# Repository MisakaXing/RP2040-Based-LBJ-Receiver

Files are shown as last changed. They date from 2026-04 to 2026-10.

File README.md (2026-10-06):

# RP2040-Based-LBJ-Receiver
# 致谢和免责

本项目参考了FLN1021/SX1276_Receive_LBJ  
本项目基于GNU-GPL开源，任何基于本项目的修改均需依相同协议开源  
本项目按“原样（AS IS）”提供，不提供任何明示或暗示的担保，包括但不限于特定用途适用性及非侵权性的担保。  
禁止用于非法用途，本项目仅作为学习POCSAG解码和SX1276无线模块的示例  
在法律允许的最大范围内，项目作者或贡献者不对因使用本项目或无法使用本项目而导致的任何直接、间接、附带、特殊、惩罚性或后果性损害承担责任，包括但不限于数据丢失、法律责任等。  

**使用本项目即表示您已理解并同意自行承担所有使用风险。**

# 1.1 硬件

您可以在/PCB文件夹中找到PCB Gerber，EDA工程文件，BOM表，原理图，在/Case文件夹找到外壳的3D模型，工程文件，请自行焊接组装

需要注意的是某些国产pico开发板的USB-C接口没有下拉电阻，这会导致无法使用PD充电器，请购买前向卖家确认好是否有下拉电阻，若不使用PD充电，可忽略本条

请提前在开发板上安装好MicroPython，版本需要大于等于1.28

推荐的电池容量是3.7v 1200-2000mah 预留的电池安装位置是35*53mm，可以修改R4/Rprog实现修改充电电流，默认充电电流是1A，Rprog和充电电流ICHG的换算关系是ICHG=1000/Rprog
PCB上电池接口为XH2.54，电池需要购买XH2.54**反向口**

PCB上不带锂电池保护电路，购买的锂电池必须**自带保护板**！

如果使用JLC打样，请确保层压结构为JLC04161H-7628，使用其他PCB制造商请使用对应的阻抗计算工具计算阻抗，阻抗线宽度为0.356mm，需求阻抗50ohm  

## 2.1软件实现原理
### 基本原理

如果您对原理不感兴趣，请直接跳转到3.1刷入程序

中国铁路列车会在821.2375Mhz上以3w功率发送POCSAG1200数据，数据类型均为numeric，列车会分两次连续发送两条数据，范例如下：  
123 23 123 #Basic msg  
列车号 速度 公里标 其中公里标格式最后一位是小数点，即12.3km  
204U2390093130U-(2 9U- (-(202011720927939053465000 #extend msg  
解码规则如下

| 字段值 | 含义 |
|---|---|
| 204U | 两位ASCII标准码表示列车等级，在这里4U=K，即K字头 |
|2390|机车类型标识号，可以从/main/rp2040-main-program/locos.json找到|
| 0093|机车号|
|30|端位，30表示无端，31为A端，32为B端|
|U-(2 9U- (-(2020|四位的GBK编码汉字，表示当前线路|
|117209279|经度|
|39053465|纬度|
|000|未知|

所有信息都只会出现在对应的位置，位号固定  

将两条信息组合即成列车完整信息  

需要注意的是并非所有线路均有扩展信息的发送，部分线路只有基础信息，甚至不少动车组列车连基础信息都不发  
### 本项目实现

通过操控SX1276的寄存器，调整其为FSK Direct模式，DIO1和DIO2分别输出1200hz时钟和采集到的bit，利用树莓派的PIO在时钟的上升沿采样DIO2的数字输出，寻找同步码并解码POCSAG，进行2bit BCH纠错后依上述解码方式解码，格式化成json返回给主函数，以上代码实现请见lbj_receiver.py

## 3.1 设备管理：LBJ Manager

原 PicoUpdater 和 LogViewer 已合并为 [LBJ Manager](lbj_manager/README.md)，源码统一在 `lbj_manager/`。固件更新、硬件检查单和历史查看共用一个窗口、一个设备选择器；接收器固件仍在 `rp2040-main-program/`。

连接接收器的数据 USB，点击「扫描设备」。只发现一台 Pico 时会自动选中，顶部显示绿色「已自动选中 Pico」；多台时请手动选择。选择普通版 `main` 或 W 版 `Wireless-Enabled`，再点击「检查并更新固件」，或用「从 ZIP 刷入」离线更新。刷入前检查硬件兼容性及固件包依赖，包含 DMA 与设备保护模块。**刷入会删除历史，先导出备份。** 更新、自检和历史读取不能同时占用串口。

固件 ZIP 可直接拖到刷入区域，先载入校验，再点击刷入并确认；拖入不会改写设备。历史页支持将 JSON / JSONL / TXT / LOG 文件拖到日志区域直接导入。

源码运行：

```sh
python3 -m pip install -r lbj_manager/requirements.txt
python3 lbj_manager/lbj_manager.py
```

预打包工具可在本项目 [Releases](https://github.com/MisakaXing/RP2040-Based-LBJ-Receiver/releases) 查找；旧 Release 中的两个独立工具不包含本次整合更新。Apple Silicon 的 `.app` 构建配置见 `lbj_manager/LBJ Manager.spec`。

*如果要使用自动更新功能，请确保不要更改Main.py的版本变量*
```python
Program_ver = 2.1
```
## 4.1 历史记录：LBJ Manager

在 LBJ Manager 的「历史记录」页读取或导出设备历史，也可导入 SD 卡中的 JSONL 文件，按车次、车型和时间筛选，查看坐标与原始报文。设备读取采用分段传输和 SHA-256 校验；读取时暂停接收，结束后重启恢复，少量未落盘记录可能丢失。

普通版机内历史最多保存2000条；实际剩余空间不足时会提前停止保存，并显示红色 MEM FULL，实时接收和显示不受存储满限制。固件预留16KB空间，并在每次写入前检查本次写入所需的整块空间。格式化机内历史后可恢复保存；历史不会自动覆盖。同时可外接SD卡扩展，SD卡必须格式化成FAT32格式才能被识别

SD卡热插拔功能因影响屏幕刷新已被取消，在开机状态下插入SD卡需要在设置中手动Mount-SD

W 版机内历史最多保存9999条，桌面查看器分批加载，避免一次性插入全部记录导致界面长时间无响应。

## Known Issues
当前代码理论上兼容RP2040（pico1）和RP2350（pico2）但是Pico2会出现各种不可预知的问题比如屏幕花屏，反色等，建议各位使用pico1  

## Update Log Jun2 2026
PCB上增加了一组肖特基二极管，现在休眠状态下按电源键也可以唤醒屏幕了  

重构了屏幕驱动，加快了屏幕刷新速度  

SN码来源更改为Pico的芯片唯一ID的Base36格式，故刷入器的SN码写入功能已被弃用，刷入器加入了硬件焊接检查功能

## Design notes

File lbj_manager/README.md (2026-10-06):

# LBJ Manager

PicoUpdater 与 LogViewer 的整合版，版本 `3.0.5-preview`。一个窗口、一个设备选择器，包含「设备管理」和「历史记录」两页。仓库内原来的两个工具目录已由本目录替代。

## 使用

安装 Python 3.11 或更高版本及依赖，运行唯一的主入口：

```sh
python3 -m pip install -r lbj_manager/requirements.txt
python3 lbj_manager/lbj_manager.py
```

Apple Silicon 版 `LBJ Manager.app` 内嵌 Python 和依赖，可直接双击。没有开发者证书签名或公证；其他 Mac 的安全设置可能要求手动允许打开。复制整个 `.app`，不要只复制里面的可执行文件，也不要破坏 Framework 的符号链接。

## 工作流程

- 接收器接入 USB 后点击「扫描设备」：唯一 Pico 自动选中，在顶部设备选择器旁显示绿色「✓ 已自动选中 Pico」和端口，底部也显示扫描结果。启动时自动选中同样有提示；后台扫描不抹掉确认，不切换设备。多台设备时手动选择。没有检测到 Pico 或扫描失败时不能刷入、读取或自检。
- 设备管理：选择普通版或 W 版，在线更新、强制刷入、离线 ZIP 刷入和硬件检查单。刷入前复核硬件兼容性。**刷入会清除设备历史，先到历史页导出备份。**
- 历史记录：读取设备、导出原始 JSONL、导入本地日志，按车次、车型、时间筛选，查看坐标、地图与原始报文。9999 条记录分批显示，未知速度保持 `---`。
- 更新、自检、读取和导出共用串口锁，不能同时操作同一台或另一台接收器。预检取消后尝试重启恢复接收；恢复失败、USB 拔出和部分写入会明确提示，不宣称设备已经恢复。
- 读取设备历史会暂时停止接收并在结束后恢复。硬件检查也会暂停接收。界面导航和设备扫描本身不会停止接收。
- 页面快捷键：Windows / Linux 使用 Ctrl+1、Ctrl+2，macOS 使用 ⌘+1、⌘+2。显式绑定 `KeyPress`，不匹配鼠标按键。
- 刷入后重启：发送指令后释放旧串口，不再等待重启指令的 EOF，避免 Windows 在 USB 断开时出现 `ClearCommError`。在线和 ZIP 刷入都检查同一接收器的 USB 断开、重连；未确认时显示「文件写入完成，重启待确认」，不会重复重启或误报固件运行正常。USB 重连不等于屏幕、射频已通过测试，仍需观察设备。

## 拖拽导入

- ZIP：将一个固件 ZIP 拖到设备管理页的「拖入固件 ZIP」区域，或「从 ZIP 刷入」按钮。软件只在电脑上校验包内版本、当前分支、运行文件与 DMA / 保护依赖；通过后显示文件名和版本。点击「刷入已载入 ZIP」才进入原有硬件预检与清空数据确认流程。**拖入本身不访问串口、不刷写、不清历史。**切换固件分支会清除已载入的 ZIP，刷入前会再次校验。
- 日志：将一个 `.json`、`.jsonl`、`.txt` 或 `.log` 历史记录文件拖到历史页的「拖入日志文件」区域，或「导入日志」按钮，直接开始后台解析。无效文件不覆盖当前已载入的记录。
- 支持中文、空格与花括号路径。多文件、文件夹、拖错区域和任务进行中的拖入会给出底部提示。
- 原有文件选择按钮保留。拖拽使用 [TkinterDnD2 的原生 TkDND 支持](https://github.com/Eliav2/tkinterdnd2)，Apple Silicon App 已内嵌 arm64 库；源码环境缺依赖时会明确提示并回退到按钮。

## DMA / 新增文件

两个分支的在线清单与离线 ZIP 都识别 `pio_dma_rx.py` 和 `device_protection.py`，依赖文件先写、`main.py` 最后写。W 版另含 `history_store.py`、`wireless_portal.py`。

`3.0.5-preview` 修复 W 版遗漏 `boot.py` 的问题：两版的在线更新与 ZIP 都保留此文件，在 `main.py` 前写入，恢复 `STARTING... / LOADING FIRMWARE` 开机画面。主程序使用 `_boot_display` 交接时，包内缺少 `boot.py` 会在刷入确认之前被拒绝；开机文件同样接受语法和 UTF-8 校验。没有早期开机画面交接的旧固件仍可不带 `boot.py`。**旧 App / exe 不会自动获得这项工具修复，必须使用重新打包的工具。** 已丢失开机文件的设备不会因电脑源码修改自动恢复，需要补写匹配该硬件的 `boot.py`；无需为此清空历史或整机刷入。

整合版额外解析包内 Python 文件的本地模块依赖：新固件如果导入 DMA / 保护模块，ZIP 或在线下载必须包含对应文件；语法错误、缺文件、无效 UTF-8 均在刷入前阻止。没有新增依赖的旧固件仍可使用。**这不是设备端逐字节刷写校验**：复制仍依赖 mpremote 的写入结果；历史导出则使用长度与 SHA-256 校验。

W 版核心自检已按当前硬件读取 GP46 的 VSYS/3，不再沿用旧的 GP41 电池测量；普通版保留 GP27 外部电池检测。

## 开发与测试

`lbj_manager.py` 是直接维护的唯一主入口，已内联两套主程序和历史传输引擎，不依赖旧工具目录或生成脚本。硬件自检使用同目录的 `solder_check.py` 与 `diagnostic_drivers/`。原有更新、检查单和历史传输的回归测试已迁入本目录，直接测试整合版，不需要恢复旧源码。

```sh
python3 -m unittest discover -s lbj_manager/tests -v
python3 lbj_manager/tests/gui_smoke.py /private/tmp/lbj-manager-gui
python3 lbj_manager/tests/drag_drop_smoke.py /private/tmp/lbj-manager-drop
```

GUI 测试创建真实 Tk 窗口，但 USB、下载与自检传输使用模拟对象，不会操作真实接收器。测试详情与边界见 `TEST_REPORT.md`。

原随附的 RTC 校时脚本保留在 `rtc_sync_gui.py`，可单独运行 `python3 lbj_manager/rtc_sync_gui.py`。它不在主 App 的导航里；使用时不要同时在 Manager 中对同一设备执行串口任务。

打包：在 arm64 Python 环境运行 `python3 -m PyInstaller "lbj_manager/LBJ Manager.spec"`。

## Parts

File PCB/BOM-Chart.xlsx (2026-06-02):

位号 | 值 | 封装 | 备注
U0 | N/A | SX1276模块 | 要868mhz (https://item.taobao.com/item.htm?id=560578002124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)
R1 | 0.4R | R0603
R2,R3 | 1K | R0603
R4 | 1K | R0603 | Rprog,需要修改充电电流的话更改此电阻
R5,R6 | 10K | R0603
R9,R10 | 4.7K | R0603
R7,R8 | 100K | R0603
C1,C2 | 10uf | C0603
C3,C4 | 0.1uf | C0603
U7 | DS3231S# | SOIC-16
U2 | TP4056 | ESOP8
D1 | N/A | LED0402 | 红色
D2 | N/A | LED0402 | 绿色
U1 | N/A | TFT2.8 | ILI9341驱动，2.8寸，不需要触摸
U8 | AO3401 | SOT23 | PMOS
U3 | SI2302 | SOT23 | NMOS
P1 | N/A | XH2-2.5490° | 90度卧式xh2.54接口
SW1,2,3,4,5 | N/A | 6X6X8 | 卧式直插按键开关
U4 | EC190708 | EC190708
J1 | BUZZER | 0905 | 3v驱动 有源
U6,U10,U11 | 1N5819 | SOD323 | 肖特基二极管
U5 | N/A | N/A | 树莓派pico开发板
U9 | N/A | SMA-KE | 卧式沉板SMA母头座子，直头偏脚，内孔
N/A | 2000mah | N/A | 电池最大大小为34x53x8mm 3.7V
N/A | M3*7+4螺柱 | N/A | 4个，用来架高屏幕
N/A | M3螺母 | N/A | 4个，在PCB背面固定螺柱
N/A | M3*8螺丝 | N/A | 8个，固定开发板和固定屏幕
N/A | 2.54排针4p | N/A | 1个，屏幕的SD卡引脚通常不焊排针，需要自己焊上

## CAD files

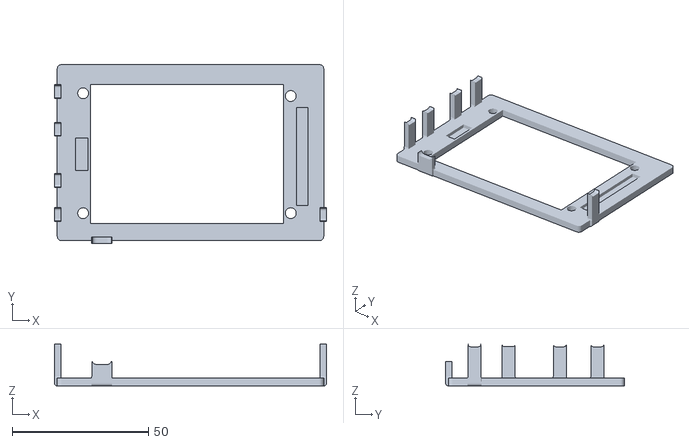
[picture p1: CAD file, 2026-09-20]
Case/CASE_V13_TOP_SCREEN_EDGE_IN0p7_TOTAL.stl
99.8 x 65.6 x 15.4

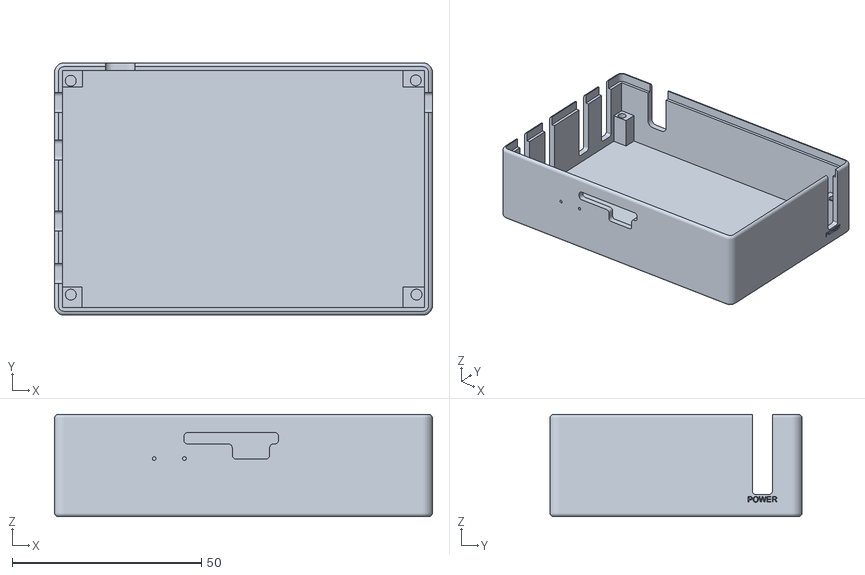
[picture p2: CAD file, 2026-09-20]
Case/CASE_V13_BODY_PCB_CLEARANCE_0p25.stl
99.8 x 66.6 x 27.0

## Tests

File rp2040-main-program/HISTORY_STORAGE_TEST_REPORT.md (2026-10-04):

# 普通版 5.12：历史容量与剩余空间保护

日期：2026-10-05（北京时间）。本次只更新普通版，未改 W 版或射频/DMA 配置。

## 行为

- 历史上限及 ABOUT 页同步为 2000 条；不会自动覆盖或截掉旧记录。
- 预留 16 KiB（不是 5 KiB）。写入前按 `statvfs` 的可用块数检查空间，额外计算本条 UTF-8 JSON 需要的整块空间及两个写入周转块。
- 达到条数上限或空间不足，持续显示红色 `MEM FULL`，停止历史队列和 Flash 追加；实时解码、显示和独立 SD 日志不受此限制。
- 文件系统读取、空间检查或写入异常显示 `SAVE ERR`，停止反复重试。只有写入与关闭/flush 均成功才发布索引、增加条数。
- 格式化历史后重新建立索引并检查空间，允许恢复保存。重启也重新检查；未完成的尾行会阻止继续追加，不会悄悄删除。
- 2000 是最大条数，不承诺任意长度的完整报文都能存满：若实际空间先不足，则提前保护。

## 自动测试

| 测试套件 | 结果 |
| --- | --- |
| 普通版固件 | 104 项通过（含 28 项新增存储测试） |
| Log Viewer | 27 项通过 |
| PicoUpdater | 75 项通过 |
| 合计 | 206 项通过 |

覆盖条数边界、预留空间与整块边界、大记录、Unicode 字节偏移、可用块/块大小、空间检查失败、ENOSPC、短写、关闭失败、队列清理、旧记录超过新上限、不完整尾行、格式化重启用、存储让步于射频积压和写入间隔、SD 独立保存、警告优先级、仅状态变化时刷新、停写后 BASIC/EXT/FULL 画面继续更新。

## 普通 Pico 实机

1. **Unicode 保存/索引：通过。** 两条含中文车型的 JSON 实际写入临时文件；第二条字节偏移与第一条实际长度一致，读取内容相同。
2. **真实 2000 条边界：通过。** 临时文件中先写入并扫描 1999 条短样本，随后使用生产保存函数写入第 2000 条；索引和条数均为 2000。再尝试 10 次保存/入队均被拒绝，文件大小保持 278,000 字节，末条可正确读取。此测试不意味着 2000 条长 FULL DATA 报文必然放得下。
3. **真实低空间：通过。** 使用临时填充文件将实际 Flash 空闲压至 24,576 字节。生产策略在追加前触发保护，历史文件仍为空、索引和计数均为零；后续入队被拒绝。此次拒绝约 9.8 ms。
4. **空间恢复：通过。** 清除临时填充文件后保护仍锁存；按格式化同样的初始化路径重新检查，保存恢复正常。
5. **PIO/DMA—解码—LCD—Flash：通过。** 32 个不同车次的已知完整 POCSAG 样本通过实际 PIO 状态机、DMA 和生产解码器，不是直接注入 UI 回调。正常保存阶段 16 条全部更新屏幕并落盘；RAM 中模拟空间保护阶段另外 16 条仍更新屏幕、但新增历史为零。同步增加 32，不可纠正码字增加 0，DMA 溢出/丢弃、回调错误及 UI 丢弃均为 0。存储服务最大用时约 138 ms。
6. **清理、重启、读回：通过。** 全部临时填充/样本文件已删除，真实历史未被测试样本污染。机内 5.12 `main.py` 与提交源码逐字相同，射频/DMA/保护依赖与本地相同，配置与升级前备份逐字相同；最后硬件重启恢复正常程序。

第 5 项为数字接收链路测试，不是空口发射、天线或现场接收率测试。测试脚本仅在 RAM 中使用无 GPIO 输出的 PIO 数据源，结束后硬件重启撤销全部测试状态；未改写射频库、DMA 库或配置文件。

## 真实接收观察边界

收尾被动日志 75 秒中，主循环及射频线程运行，DMA 启用，线程/SPI/回调错误和丢弃均为零；截至最终状态快照，新启动实例 `words=0`、`syncs=0`。没有收到新的自然空口报文，因此不能将此版本宣称为已解决此前所有“不接收”现象，或把缺少自然报文视为接收率验证通过。

## 用户数据处理

经用户明确授权，原有 2006 条历史已在备份验证后清空；保留机器配置及其他文件。原历史 976,885 字节完整 JSON 校验通过，备份位于 Mac：

`/Users/xinghening/Documents/Codex/LBJ_STANDARD_STORAGE_GUARD_2026-10-05/history-before-clear.jsonl`

最终文件系统空闲 983,040 字节；实机测试临时文件已删除，无新增测试车次留在真实历史。

原始测试日志、固件读回哈希及部署前配置备份保存在同一 Mac 目录，不包含在 Git 提交中。

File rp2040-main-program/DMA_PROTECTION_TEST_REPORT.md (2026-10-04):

# DMA、温度与低电量保护验证

> 本文保留保护功能阶段的原始测试记录。后续 DMA/AFC 修复与 5.11 / 5.13-W 提交前验证见 `DMA_RECOVERY_TEST_REPORT.md`；下文版本和“未推送”状态对应当时测试阶段。

日期：2026-10-04。普通版 5.10；W 版 5.12-W。两台设备已刷写，未提交或推送 GitHub。

## 行为

| 条件 | 两版行为 | W 版附加行为 |
| --- | --- | --- |
| 核心温度 >45°C | 温度读数标红 | 相同 |
| 核心温度 >60°C | 顶栏红色 HIGH TEMP | 关闭 AP；无线设置显示高温禁用原因 |
| 温度降至 ≤55°C | 解除无线高温锁定 | 依照原先保存的无线开关恢复；不会擅自开启原本关闭的无线 |
| 电池 <10%，无 USB 供电 | 顶栏红色 LOW BAT | 相同 |
| >60°C 且 <10%，无 USB 供电 | 两项警告每 2 秒交替 | 相同 |
| 电量 0%（补偿后的电压 ≤3.45 V），无 USB 供电 | 提示停收约 1 秒，关闭射频采集与屏幕，确认停收后降至 18 MHz | 同时关闭 AP |
| 保护后检测到 USB 供电 | 连续两次确认后硬件重启，重新完成 POST | 相同；保留原设置 |

普通版保留原 +0.174 V 电池补偿；W 版保留 1.07 倍补偿。普通版正常运行 200 MHz，W 版 150 MHz，不改变正常接收频率或射频参数。USB 状态每秒采样；温度与电池每 5 秒采样。警告交替与局部重绘无阻塞等待；仅低电量终止接收流程包含提示和保护等待。

## DMA

普通版已移植 W 版的 PIO→DMA 采集路径：512 个 32 位字的环形缓冲，两个 DMA 通道。运行时检查 DMA 支持，初始化失败回退原 FIFO。保留溢出与丢字计数，不把“队列没有丢弃”等同于射频完全没有丢码。

停收时关闭 PIO、数据与重载 DMA，并使 SX1276 进入 FSK Sleep。射频参数仍为 821242368 Hz、PPM 6、12.5 kHz 带宽、硬件 AFC、AGC 关闭、LNA 0x23。PicoUpdater 已同步模块清单及刷写顺序；仍兼容旧版固件包。

## 自动测试

- 普通版固件：58 项通过；W 版固件：220 项通过。
- PicoUpdater：普通分支 75 项、W 分支 76 项通过。
- 合计 429 次测试执行；两个分支有重复用例，不代表 429 个独立测试场景。
- W 网页真实 TCP/EventSource 与 Chrome 三客户端测试通过，覆盖历史权限、实时回退、20 秒超时、时间和导航。
- 手机、平板、电脑布局测试通过，无横向溢出；360×640 小屏仍需要纵向滚动，不承诺所有屏幕一屏放下。

## 实机专项

普通板 S/N：e66368254f677426。W 板 S/N：018540bc4336e6b4。

两板实测 DMA 连续有序字、环形回绕、重载计数、故意溢出计数及停止/重置。以独立 PIO 状态机生成输入，暂停消费 1.5 秒仍保存 56 个字，PIO FIFO 未满。

两板实际执行 LCD 警告绘制、射频与 DMA 停止、射频 Sleep、关闭背光、18 MHz 降频及重启恢复。温度、电量和保护中的 USB 插入返回值采用 RAM 注入，不加热设备、不耗尽电池，不制造历史车次。W 板实际关闭/恢复 AP，并验证无线高温提示及 55°C 回差。

最初 W 板在停收退出 core 1 后的保护流程出现 USB 无响应。改为停收后让 core 1 保持空闲驻留，避免退出线程；修改后完整通过 18 MHz 保护与 USB 重启路径。结果不支持“18 MHz 必然过低”，但底层线程退出/Flash 锁定关联仍是推测，未证明具体固件根因。生产代码没有加入测试用看门狗。

停收异常分支已加回归测试：只有 receiver.stop 成功才确认已停收；若失败，保护不执行降频。

## 普通版六分钟联合测试

按正常接收→历史翻页→正常接收→模拟高温低电量并翻页运行。实际绘制 273 次历史翻页，历史条数 1204→1222，持续接收真实射频车次。两项顶栏警告均出现。

DMA 溢出、DMA 丢字、FIFO 满、接收线程异常及 UI 队列丢弃均为 0；DMA 峰值 14/512 字。仍存在无线信道 BCH 不可纠正码字及重同步，不能据此断言所有空中报文均成功接收。

首次逐行核验 1229 条落盘 JSON 均有效；追加接收后的最终核验为 1274 条，仍无无效行，首/中/末记录读取正确，待写队列清零。设备主程序和新模块与本地逐字节一致，移除临时测试入口后硬件重启恢复正常 DMA 接收。检查脚本曾误将 REPL 的不可变总数快照当作实时计数；已改为与实际可变索引长度对照，确认不是历史文件损坏。

## W 版六分钟联合测试

同样执行四阶段对照，机内历史共绘制 316 次（正常 157、高温低电量 159）；SSE 所有者发起 119 次历史请求，其中 118 次完成，阶段切换时最后一项主动取消，无错误响应。温度注入 61.2°C 时实际 AP 关闭，HIGH TEMP/LOW BAT 均出现；恢复真实温度 43.4°C 后，按原保存的开启状态恢复 AP。

初始无同步，出现此前已存在的 profile_op_mode 恢复；约第 5 分钟才开始捕获射频。历史 1639→1640，采集超过 2600 个字；DMA 溢出、丢字、FIFO 满、UI/历史队列丢弃、线程异常、网页及存储错误为 0。仍存在 BCH 错码和重同步，不能承诺全报文接收。此轮没有在“网页历史负载开启”阶段获得实际射频车次，因此不单凭本轮证明该组合下接收性能完全不受影响。

最终逐行核验 1640 条历史全部有效，首/中/末记录可读取，待写队列为 0；七个部署文件逐字节核验，正常主程序已恢复，无临时测试入口。硬件重启后 AP 与 512 字 DMA 接收正常初始化。

## 测试范围

最后对正常主程序并行采集 65 秒日志：两台均继续采集射频字流，DMA/FIFO 溢出与丢字、线程错误、UI 丢弃仍为 0。W 版 AP 开启时出现实际地址与解码活动，网页和存储错误为 0；仍有信道错码，未将其掩盖为“全报文通过”。

未切换 Mac 网络，未执行真实手机经热点的端到端测试；板上网页压力测试使用 RAM socket 替身调用生产处理逻辑。未重新插入 SD 卡、人工逐个按键、物理拔插 USB 或实测耗尽电池。此前现存历史未格式化或删除；最早诊断快照前暂停可能损失当时尚未落盘的队列记录。短时压力测试不替代数日老化或有已知发送总数的射频丢包率测量。

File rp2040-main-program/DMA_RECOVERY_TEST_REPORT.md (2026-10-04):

# DMA/AFC 修复及提交前验证

日期：2026-10-04（北京时间）。普通版发布版本 5.11；W 版 5.13-W。

实机专项在递增版本号之前完成，设备测试时版本为 5.10 / 5.12-W。
本次发布仅在已验证执行代码上递增版本号，并更新测试和文档；没有再次刷写设备。

提交前自动回归：普通版固件 76 项、W 版固件 238 项通过；对应 PicoUpdater 测试 75 / 76 项通过。合计 465 次测试执行，两分支包含重复场景。测试需从固件目录运行，或设置 PYTHONPATH=rp2040-main-program。

## 修复范围

- 保留 512 个 32 位字的 DMA 环形缓冲、射频频率、PPM、带宽、增益及正常 CPU 频率。
- 连续直接模式的 AFC 不会自动为每个新突发重新计算。未同步时仅在无积压的新前导码上安全重捕获；连续采样但 15 秒没有同步时有界恢复。已同步负载不重启，寄存器查询最多每秒四次。
- 重新捕获按序停止 PIO/DMA、清 FIFO/移位状态、恢复 PIO 指令入口、重置 DMA，再请求带 PLL 重锁的接收重启。
- 只放行 PLL 已锁定但 ModeReady/RxReady 尚未就绪的特定 FSRx 状态，避免原工作模式检查反复重新配置；其他配置错误仍检查。
- BCH 纠错表改为 1024 个 uint32 的定长数组。实机重建旧字典约占 14048 字节，新数组数据区 4096 字节，另有少量对象开销；接收线程启动前 GC。
- 诊断附加 RAM 占用曾使普通版线程栈及历史索引分配失败；这不证明所有正常程序不同步都由内存问题引起。
- 同步已完成的 DMA、温度和低电量保护改动；W 版同时包含网页历史功能。
- PicoUpdater 在两种硬件配置中上传 DMA / 保护模块，并在 main.py 之前写入，保留对旧固件包的兼容。

## 实机结果

设备：普通版 e66368254f677426；W 版 018540bc4336e6b4。

| 测试 | 普通版 | W 版 |
|---|---:|---:|
| 同一 DCLK/Data 同时送 DMA 与直接 FIFO | 2201 字、0 差异 | 2226 字、0 差异 |
| 完整 BASIC+EXT 输入：FIFO / DMA / 短计数重载 | 各 32/32 正确 | 各 32/32 正确 |
| 强制 +18.31 kHz AFC 错误后的实际恢复 | 约 15 秒 | 约 15 秒 |
| 最终正常程序硬件复位启动 | 5/5 | 5/5 |
| 15 分钟现场同步次数 | 28 | 10 |
| 15 分钟新增落盘历史 | 15 | 6 |
| 15 分钟 DMA 最高占用 | 35/512 | 4/512 |
| 15 分钟 DMA 溢出 / 丢字 / 线程错误 | 0 / 0 / 0 | 0 / 0 / 0 |
| 60 秒双核已知完整帧与屏幕并发 | 37 帧正确、127 次翻页 | 37 帧正确、121 次翻页 |
| W 同时处理授权网页历史请求 | 不适用 | 121 次、正确序号 |
| 全量历史解析与索引复核 | 1819 条、0 无效 | 2256 条、0 无效 |

完整回放共 192 帧、6720 输入字，双核并发另有 74 帧；模拟报文不写入历史。
并发后普通版实存 1821 条（开始前又新增两条真实历史），W 实存 2256 条；逐条核对索引与文件序号匹配。
两板均移除临时测试程序并硬件复位，恢复正常主程序。部署时 main.py、lbj_receiver.py 与当时本地修复逐字节一致，其他核对文件与测试前备份一致。

## 验证边界

- 五轮启动是硬件复位，不是同时断开 USB 和电池的真正断电冷启动。
- 受控回放经过实际 PIO/DMA 和生产解码链路，但绕过空中射频；物理 AFC 恢复另有实际寄存器故障注入验证。
- W 网页并发实机检查使用 RAM HTTP socket 模型运行生产服务代码，不是手机经过热点的端到端测试；未切换 Mac 网络，设备 TCP 自连接超时不计入通过项。
- 现场仍有 BCH 不可纠正码字，15 分钟普通版 164、W 版 43；不能等同于精确丢包数，也不能宣称所有空中报文都收到。
- W 在部分短窗口无输入字，随后未重启或写射频寄存器就自然恢复至 572 字、1 次同步。只读检查发现 FSRx 等待前导码，DMA/PIO 正常、无积压；不据此证明两台板卡灵敏度相同或没有弱信号漏收。
- 没有已知总发送数的受控 RF 源，不给出绝对接收率。短测不替代数日老化。

依据：[Semtech SX1276/77/78/79 数据手册，第 52、60、96–98 页](https://cdn-shop.adafruit.com/product-files/3179/sx1276_77_78_79.pdf)、[MicroPython DMA 文档](https://docs.micropython.org/en/latest/library/rp2.DMA.html)。

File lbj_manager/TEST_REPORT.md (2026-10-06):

# LBJ Manager 测试记录

日期：2026-10-06。版本：`3.0.5-preview`。环境：Apple Silicon Mac，Python 3.11.5，真实 Tk 窗口，PyInstaller 6.19.0。

## 结果

| 范围 | 结果 |
| --- | --- |
| 合并版自动回归 | 开机文件交付修复后 271 项全部通过，无跳过；新增 7 项交付专项，保留前轮 27 项重启测试 |
| 真实窗口集成与压力测试 | 开机文件交付修复后重跑 65 项通过；两套数字快捷键与鼠标导航事件均通过，无 Tk 回调异常 |
| macOS 原生拖放事件链 | 24 项检查通过，TkDND 2.10.2，无串口访问 |
| 独立目录运行 | 前轮将新目录复制到仓库外，232 项回归全部通过 |
| 已连接 Pico 的扫描按钮检查 | 前轮 12 项通过；本次重跑未检测到 Pico，未执行串口操作 |
| arm64 `.app` 与复制版本 | 本轮 3.0.5 新包与复制版本 21 项通过，启动/强制结束日志无异常；内嵌程序全部字节码及常量与测试源码匹配。未构建 Windows exe |
| 原更新 / 自检 / 历史回归迁移 | 102 项保留在新目录，已计入上述 232 项 |

旧硬件检查测试中强制要求 W 核心自检读取 GP41 的断言，已随测试迁移改为 GP46 VSYS/3，并明确断言不使用 GP41；不再跳过。另有测试验证引脚、取样中位数与换算。

2026-10-06 目录迁移：移除仓库根目录的 `pico_updater/` 与 `log-viewer/`，统一为 `lbj_manager/`。旧回归直接导入整合主入口，不再读取旧目录。移除依赖旧源码的生成器与测试回放加载器，直接维护 `lbj_manager.py`；保留原随附 RTC 校时脚本。旧目录的完整备份在仓库外，接收器固件没有改动。

## 已覆盖

- 全局串口任务锁：40 个线程同时抢占只能有一个持有者；旧任务、伪造同值令牌不能解除新任务锁。
- 设备选择：单 Pico 首次选择、启动后插入并点击扫描、多 Pico 手动选择、非 Pico 串口、Debug Probe、拔出和更换设备；后台扫描不自动替换操作目标。点击扫描会给出完成 / 未发现 / 多台 / 失败提示；扫描失败禁用操作，重试成功恢复。
- 自动选中提示：启动时与点击扫描时，顶部选择器旁持续显示绿色「✓ 已自动选中 Pico」与端口；底部同时给出文字确认。后台扫描不抹掉提示；手动选择显示「已选中 Pico」，断开或扫描失败不保留绿色确认。
- 导航快捷键修复：用户在 Windows 实机复现并确认旧 `<Command-1>` 被解析为鼠标按钮，导致点击历史后又切回设备页。本地改为按平台选择 Command / Control，显式 `KeyPress-1/2`。测试检查两平台绑定字符串、页面目标及无含糊数字绑定；真实 Tk 测试向导航按钮 Label 注入鼠标按下 / 松开事件，验证来回切页，并在 Mac Tcl 引擎中验证 Ctrl 数字键事件。这不等同于本机完成 Windows 操作系统实测。
- 文件拖放：通过真实 TkDND 的 macOS enter / position / drop 事件链验证区域、按钮及其 Canvas / Label 子控件。中文、空格、花括号与大写后缀；单文件、类型 / 区域错误、损坏 ZIP、分支不符、设备忙碌；ZIP 仅载入、再次点击才进入既有预检确认，分支切换清除已载入包；日志直接导入、无效记录保持原数据，线程失败释放加载状态。明确禁止串口、刷写与设备历史命令。
- 主线程调度：1000 个后台回调有序执行，不从后台调用 Tk；任务失效、窗口关闭和回调超量不会误执行更新。
- 更新与恢复：取消、兼容性拒绝、线程启动失败、命令无输出或没有换行时的超时、USB 恢复失败、部分刷写、刷写中关闭窗口。
- 重启专项：重启不跟随 EOF、不退出旧 raw REPL，关闭旧串口后仅枚举 USB。Windows `ClearCommError`、发送失败、关闭失败、枚举失败、断开后未返回、未观察到断开均不能误报确认；同一 USB 序列号变更 COM 端口可识别，其他接收器不能冒充。在线与 ZIP 刷入共用完成提示；复制失败不发送重启，重启待确认不重复发送，警告只弹一次，普通写入错误仍失败。
- 固件包：普通 / W 两分支的在线清单、平铺 / GitHub 目录 / Windows 分隔符 ZIP；DMA 与保护模块先于 `main.py` 写入；直接读取两工作树的当前固件生成 ZIP，逐文件对照提取内容。
- 开机文件交付修复：移除旧测试中错误的“W 清单不包含 boot.py”断言。两版实际固件 ZIP 必须保留含 `LOADING FIRMWARE` 的 boot.py；新增测试覆盖 W 在线下载完整字节、两版三种 ZIP 路径、在线与 ZIP 两种清空/复制工作流（共 12 组子场景），验证 boot.py 写在 main.py 前，模拟设备启动交接保留画面。新版缺 boot.py 在确认之前拒绝；boot.py 写入失败保持部分刷入警告、不写 main.py、不重启。无交接的旧固件仍可刷入，注释/普通字符串不误判，语法损坏或非 UTF-8 的 boot.py 拒绝。
- 新增文件负向测试：新固件缺 `pio_dma_rx.py` 或 `device_protection.py` 时在确认刷入之前拒绝；旧固件未导入这些模块时仍接受。语法损坏、无效 UTF-8、不可读源码拒绝；注释中的 import 不误判。
- 历史传输：4096 字节分段、完整长度与 SHA-256、中文跨块、数据损坏、截断、空文件、恢复失败、原子导出不覆盖旧文件、读取与更新不能同时启动。
- 历史展示：9999 条全部保留，`0D139`、中文车型、五位车号和 A/B、年/月/日时/分、未知速度 `---`、零值与非法坐标、跨午夜时间筛选。
- 真实 UI：9999 条分批渲染、筛选再恢复、150 次改变记录选择、80 次页面切换、最小窗口 1120×800、单地图标记、坐标与日期不裁切。
- 检查单：嵌入设备页、运行时不离开检查单、核心通过后等待确认、W 显示 VSYS、报告结束释放锁并返回运行日志。原有按键、屏幕、蜂鸣器、SD 工作流回归测试保留。
- 打包：arm64 可执行文件、权限、Framework 符号链接、bundle 本地完整性、内嵌 mpremote、任意工作目录启动、复制整个 `.app` 后再次启动。检查可执行文件的归档，确认包含新合并 UI 与固件依赖验证函数。

快捷键修复首轮真实 GUI 压力测试：9999 条导入并渲染约 **1.00 秒**，全程约 10.50 秒；5 ms UI 心跳的最大间隔为 **148.3 ms**（不计截屏）。这些是本机测试值，不保证其他 Mac 同速。

## 边界

本轮**没有打开真实接收器串口、刷写设备、清除历史或修改射频 / 屏幕固件**。GUI 的 USB、下载与检查结果为模拟数据，不把模拟通过当作真实硬件合格。真实 USB 刷写、射频接收性能、实体按键与屏幕结果仍需后续设备联调。

重启专项在 Mac 上以模拟传输和 USB 枚举测试 Windows / macOS 分支，没有 Windows 主机或实体 USB 重连测试。USB 重连确认不代表新固件主程序或射频已启动正常；用户仍需检查屏幕与接收状态。此前 App / exe 不包含本次修复，不能继续使用旧包来验证工具修复；Windows exe 尚未重新打包。

前轮扫描专项另用 Mac 实际枚举到的 `/dev/cu.usbmodem1101` 验证了真实按钮：先重现“启动后才插入”的未选择状态，再点击扫描，确认选中、提示结果、更新 / 自检 / 读取按钮启用。测试显式禁止串口打开、设备命令与历史传输；接收器未暂停或复位。本轮目录替换及拖放更新后再次尝试扫描专项，电脑未检测到 Pico，测试在启动 GUI 前退出；本轮扫描行为由真实窗口加模拟枚举覆盖。

固件复制仍沿用 mpremote 文件复制结果，尚未加入设备端逐文件读回哈希；依赖检查不等同于刷入后的字节校验。历史导出已有 SHA-256 校验。

App 没有开发者证书签名或公证，使用打包器必需的本地 ad-hoc 完整性签名。复制启动测试发生在本 Mac，不等同于已在另一台 Mac 验证 Gatekeeper 放行。

拖放专项调用原生库实际使用的 Tcl 事件入口并经过真实绑定与异步解析；不是只有 Python 回调模拟，但未代替用户在 Finder 中手动拖动的最终体验确认。

本次快捷键最后一轮 GUI 测试的历史页、最小窗口及模拟检查单截图命令返回失败，已记录 `screenshot_warnings`；65 项状态与事件检查通过，但这轮截图不作为视觉验证成功证据。

原生 App 的强制结束测试在 stderr 记录了 Pillow `PhotoImage.__del__` 的忽略异常，启动阶段和窗口显示正常。测试脚本把启动阶段与测试强制 SIGTERM 后的日志分开保留；不能把所有退出路径都视为已验证无警告。

## 复现

```sh
python3 -m unittest discover -s lbj_manager/tests -v
python3 lbj_manager/tests/gui_smoke.py /private/tmp/lbj-manager-gui
python3 lbj_manager/tests/drag_drop_smoke.py /private/tmp/lbj-manager-drop
python3 lbj_manager/tests/scan_live_smoke.py /private/tmp/lbj-live-scan.json
python3 lbj_manager/tests/frozen_smoke.py "/absolute/path/LBJ Manager.app" /private/tmp/lbj-manager-app-test
```

原始窗口测试结果与截图保存在本机 `Documents/Codex/LBJ-Manager-2026-10-06/gui-test`；App 启动结果在同目录 `app-test`。

重启修复后的窗口测试记录在 `/private/tmp/lbj-manager-reset-gui`：65 项通过，无 Tk 回调异常，9999 条加载约 1.049 秒，最大 UI 心跳间隔 79.2 ms。这些是本 Mac 的模拟设备测试值。

开机文件交付修复后的窗口记录在 `/private/tmp/lbj-manager-boot-fix-gui`：65 项通过，无 Tk 回调异常；本轮截屏失败已单独记录，不能据此宣称视觉验证成功。交付测试使用模拟串口/网络/设备文件系统，未补写实体设备，也未验证实体板开机画面。

本轮新 App 为 `Documents/Codex/LBJ-Manager-Boot-Fix-3.0.5/dist/LBJ Manager.app`，启动与复制测试结果及截图在同目录上级的 `app-test` 中。包内编译主入口（含全部嵌套函数字节码/常量）与被测试源码一致，版本 3.0.5-preview；21 项 App 检查通过、两次截图成功，未使用开发者证书。启动测试不执行真实刷写，不能据此宣称实体设备开机画面恢复。

被测试的主入口 SHA-256：`fe823e6188a8b7d9c0caa1024226eb5fb50121c77fa25d7c6ef500c6d1132adf`。

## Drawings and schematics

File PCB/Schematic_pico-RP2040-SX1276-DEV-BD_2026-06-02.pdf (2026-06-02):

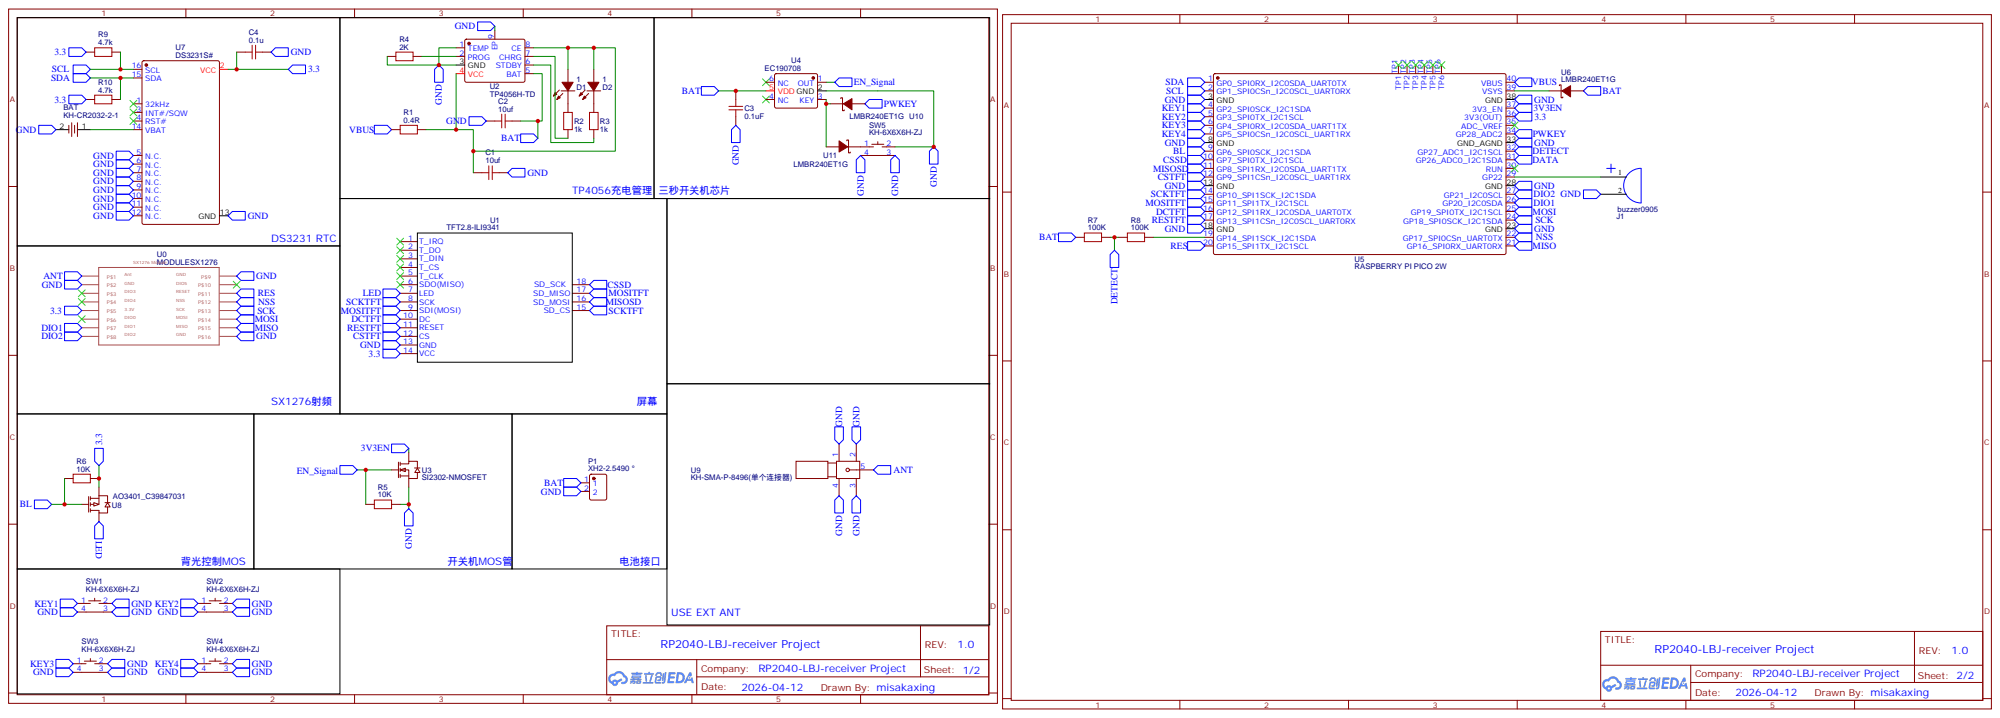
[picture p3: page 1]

Company: RP2040-LBJ-receiver Project

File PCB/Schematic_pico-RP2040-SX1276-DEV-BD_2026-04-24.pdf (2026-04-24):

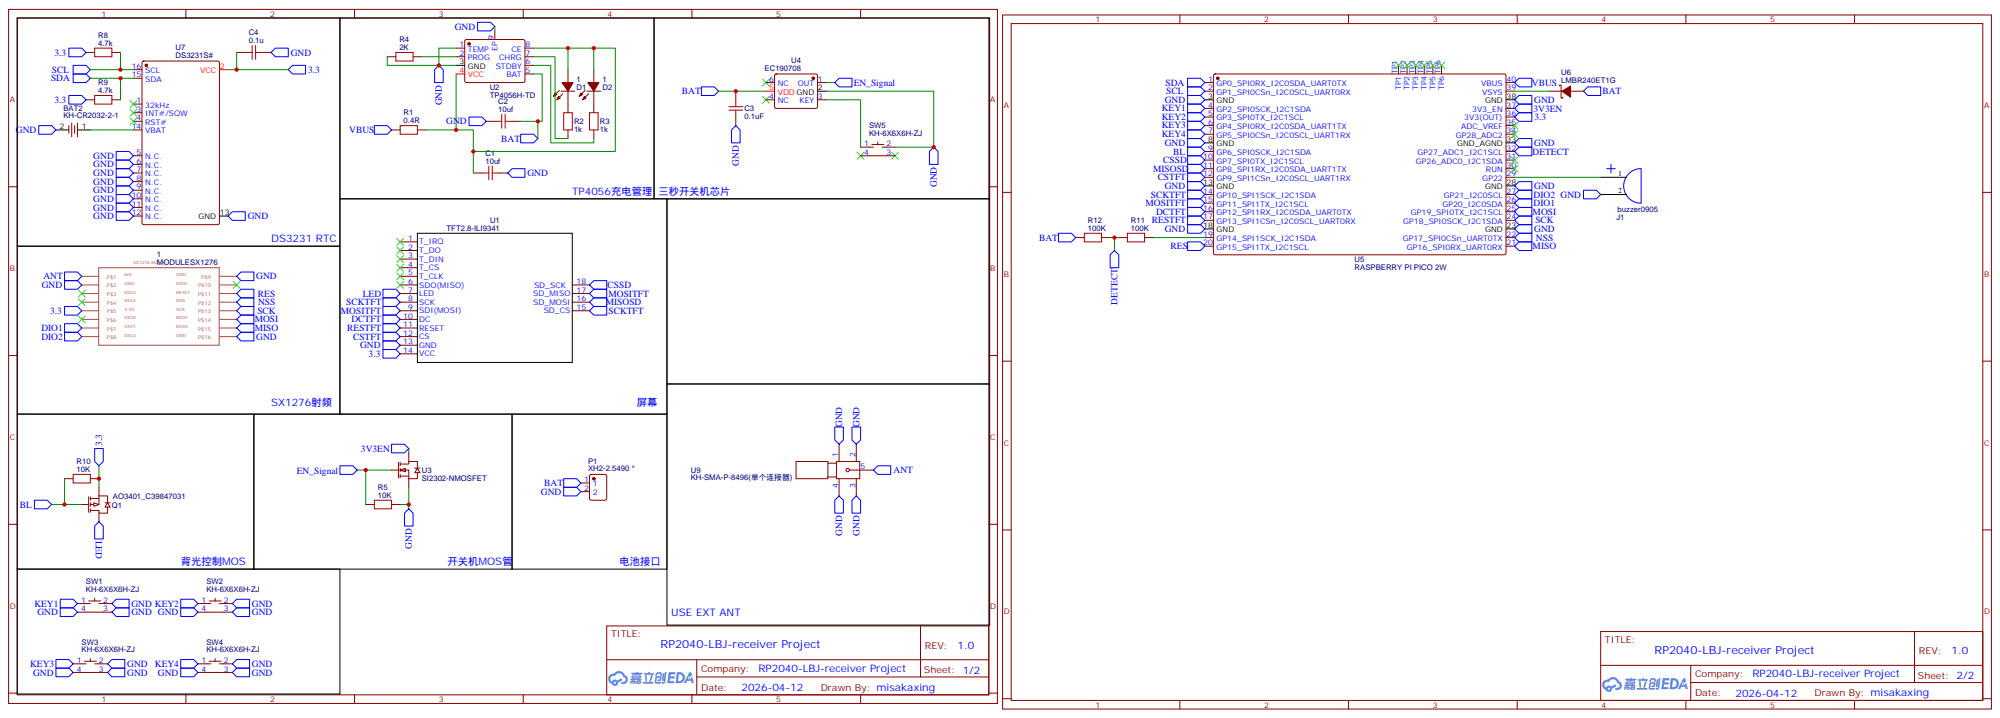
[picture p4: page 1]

Company: RP2040-LBJ-receiver Project

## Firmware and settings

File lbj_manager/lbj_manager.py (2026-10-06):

"""LBJ Manager: firmware, assembly inspection and train history.

Single desktop entry point and source of truth for the combined application.
The integration layer owns device selection, task leases and main-thread UI
dispatch. This module runs without either of the retired tool directories.
"""
import sys
if len(sys.argv) > 1 and sys.argv[1] == "mpremote_internal":
    sys.argv = [sys.argv[0]] + sys.argv[2:]
    from mpremote.main import main
    raise SystemExit(main())


# Verified history-transfer engine
"""Bounded, verified history downloads; no writes to the Pico filesystem."""


import ast


from dataclasses import dataclass


import hashlib


import os


import tempfile


CHUNK_SIZE = 4096


COMMAND_TIMEOUT = 20


class HistoryTransferError(RuntimeError):
    pass


@dataclass
class HistoryDownload:
    data: bytes
    sha256: str
    recovery_warning: str = ""


def _connect(port):
    # Also bundled by PyInstaller; no child process or command-line timeout.
    from mpremote.transport_serial import SerialTransport

    return SerialTransport(port)


def _execute(transport, command):
    output, error = transport.exec_raw(command, timeout=COMMAND_TIMEOUT)
    if error:
        raise HistoryTransferError(error.decode("utf-8", errors="replace").strip())
    return output.strip()


def download_history(port, progress=None, status=None, transport_factory=None):
    """Pause/reset the interpreter, download in small transactions, then reboot.

    Each block has its own EOF and timeout, independent of total file size.
    The initial raw-REPL reset stops the receiver's second core/timers too, so
    background radio prints cannot be mistaken for file data. main.py is not
    executed in this raw-REPL session. The final hardware reset runs it again.
    """
    def observe(callback, *args):
        # A closed/busy GUI must not prevent the finally block from rebooting
        # the receiver. Observers do not control the transport lifecycle.
        if callback is not None:
            try:
                callback(*args)
            except Exception:
                pass

    def notify(text):
        observe(status, text)

    def report(done, total):
        observe(progress, done, total)

    transport = None
    failure = None
    recovery_warning = ""
    data = bytearray()
    digest = hashlib.sha256()
    synchronized = False
    try:
        notify("正在暂停接收程序...")
        transport = (transport_factory or _connect)(port)
        # Bound low-level reads/writes too (older mpremote defaults to None).
        transport.serial.timeout = 2
        transport.serial.write_timeout = 5
        transport.use_raw_paste = False
        transport.enter_raw_repl(soft_reset=True)
        synchronized = True
        size = ast.literal_eval(_execute(transport,
            "import os as _lv_os, gc as _lv_gc, hashlib as _lv_hashlib\n"
            "_lv_gc.collect()\n"
            "_lv_file = open('history.jsonl', 'rb')\n"
            "_lv_hash = _lv_hashlib.sha256()\n"
            "print(_lv_os.stat('history.jsonl')[6])"
        ).decode("ascii"))
        if type(size) is not int or size < 0:
            raise HistoryTransferError("设备返回了无效的文件长度。")
        report(0, size)
        while len(data) < size:
            requested = min(CHUNK_SIZE, size - len(data))
            # Decode a complete bytes literal, never individual UTF-8 chunks.
            # The device holds only one small block, not the whole history.
            chunk = ast.literal_eval(_execute(transport,
                "_lv_block = _lv_file.read(%d)\n"
                "_lv_hash.update(_lv_block)\n"
                "print(repr(_lv_block))\n"
                "del _lv_block\n_lv_gc.collect()" % requested
            ).decode("ascii"))
            if not isinstance(chunk, bytes) or len(chunk) != requested:
                raise HistoryTransferError("历史文件提前结束或数据块长度不符，请重新读取。")
            data.extend(chunk)
            digest.update(chunk)
            report(len(data), size)

        notify("正在校验文件完整性...")
        remote_size, tail, remote_digest = ast.literal_eval(_execute(transport,
            "print(repr((_lv_os.stat('history.jsonl')[6], "
            "_lv_file.read(1), _lv_hash.digest())))\n_lv_file.close()"
        ).decode("ascii"))
        if remote_size != size or tail != b"":
            raise HistoryTransferError("读取期间历史文件长度发生变化，请重新读取。")
        if remote_digest != digest.digest():
            raise HistoryTransferError("历史文件 SHA-256 校验失败，未采用不完整数据。")
    except Exception as exc:
        synchronized = False
        failure = exc
    finally:
        if transport is not None:
            try:
                notify("正在恢复设备运行...")
                if not synchronized:
                    # A timed-out command can still be printing. Interrupt it
                    # and reacquire raw REPL before issuing a reset command.
                    transport.enter_raw_repl(soft_reset=False)
                # A reset has no normal EOF; do not wait for one.
                transport.exec_raw_no_follow("import machine; machine.reset()")
            except Exception as exc:
                recovery_warning = "未能确认已发送设备重启指令，请手动复位。原因：%s" % exc
            finally:
                try:
                    transport.close()
                except Exception as exc:
                    recovery_warning = recovery_warning or "关闭串口失败：%s" % exc

    if failure is not None:
        detail = str(failure)
        if "EOF" in detail or "timeout" in detail.lower():
            detail = "传输某个数据块时设备未及时响应（已读取 %d 字节）。\n%s" % (len(data), detail)
        if recovery_warning:
            detail += "\n\n" + recovery_warning
        raise HistoryTransferError(detail) from failure
    return HistoryDownload(bytes(data), digest.hexdigest(), recovery_warning)


def save_history_atomic(path, data):
    """Only replace the chosen export after all verified bytes reach disk."""
    path = os.path.abspath(path)
    fd, temporary = tempfile.mkstemp(prefix=".lbj-history-", suffix=".tmp", dir=os.path.dirname(path))
    try:
        with os.fdopen(fd, "wb") as stream:
            stream.write(data)
            stream.flush()
            os.fsync(stream.fileno())
        os.replace(temporary, path)
    finally:
        if os.path.exists(temporary):
            os.unlink(temporary)


# Firmware-update engine
import sys


import os


import re


import threading


import tempfile


import subprocess


import zipfile


import shutil


from urllib.parse import quote


import requests


import customtkinter as ctk


import serial.tools.list_ports


from tkinter import messagebox, filedialog


ctk.set_appearance_mode("Dark")


ctk.set_default_color_theme("blue")


COLORS = {
    "bg": "#101317",
    "sidebar": "#15191E",
    "surface": "#1A1F25",
    "surface_alt": "#20262D",
    "border": "#303841",
    "text": "#F3F6F8",
    "muted": "#96A1AC",
    "teal": "#26B8A6",
    "teal_hover": "#209A8C",
    "blue": "#4C8DFF",
    "blue_hover": "#3C73D2",
    "amber": "#E9AD4A",
    "green": "#45B97C",
    "green_hover": "#389966",
    "red": "#E46A6A",
    "red_hover": "#BD5555",
}


GITHUB_REPO = "MisakaXing/RP2040-Based-LBJ-Receiver"


TARGET_DIR = "rp2040-main-program"


STANDARD_CHANNEL_LABEL = "标准版（main / RP2040）"


WIRELESS_CHANNEL_LABEL = "无线 W 版（Wireless-Enabled）"


DEFAULT_CHANNEL_LABEL = STANDARD_CHANNEL_LABEL


COMMON_RUNTIME_FILES = (
    "HZK16",
    "boot_post.py",
    "ili9341.py",
    "lbj_receiver.py",
    "locos.json",
    "rtc_ds3231.py",
    "sdcard.py",
)


FIRMWARE_BRANCHES = {
    STANDARD_CHANNEL_LABEL: {
        "label": STANDARD_CHANNEL_LABEL,
        "branch": "main",
        "family": "rp2040",
        "hardware_hint": "仅适用于 RP2040 Pico 标准接收器",
        "runtime_files": COMMON_RUNTIME_FILES + ("main.py",),
        "optional_runtime_files": ("boot.py", "pio_dma_rx.py", "device_protection.py"),
    },
    WIRELESS_CHANNEL_LABEL: {
        "label": WIRELESS_CHANNEL_LABEL,
        "branch": "Wireless-Enabled",
        "family": "waveshare_w",
        "hardware_hint": "仅适用于 Waveshare RP2350B-Plus-W",
        "runtime_files": COMMON_RUNTIME_FILES + (
            "history_store.py",
            "wireless_portal.py",
            "main.py",
        ),
        "optional_runtime_files": ("boot.py", "pio_dma_rx.py", "device_protection.py"),
    },
}


PROGRAM_VERSION_RE = re.compile(
    r"\bProgram_ver\s*=\s*(?P<value>[\"'][^\"'\r\n]+[\"']|[0-9][A-Za-z0-9._-]*)"
)


HARDWARE_PROBE_PREFIX = "LBJ_HW_PROBE_V1"


MIN_WIRELESS_FS_BYTES = 12 * 1024 * 1024


HARDWARE_PROBE_SCRIPT = """import sys
import os
import machine

def safe(value):
    return str(value).replace("|", " ").replace("\\r", " ").replace("\\n", " ")

implementation = sys.implementation
build = getattr(implementation, "_build", "")
impl_machine = getattr(implementation, "_machine", "")
try:
    uname_machine = getattr(os.uname(), "machine", "")
except Exception:
    uname_machine = ""

network_ok = 0
try:
    import network
    wlan_type = getattr(network.WLAN, "IF_STA", None)
    if wlan_type is None:
        wlan_type = getattr(network, "STA_IF", None)
    if wlan_type is None:
        raise OSError("STA interface missing")
    network.WLAN(wlan_type)
    network_ok = 1
except Exception:
    pass

pins_ok = 0
try:
    machine.Pin(41)
    machine.Pin(42)
    pins_ok = 1
except Exception:
    pass

fs_bytes = 0
try:
    values = os.statvfs("/")
    fs_bytes = int(values[0]) * int(values[2])
except Exception:
    pass

print("LBJ_HW_PROBE_V1|build=%s|impl_machine=%s|uname_machine=%s|platform=%s|network=%d|pins_41_42=%d|fs_bytes=%d" % (
    safe(build), safe(impl_machine), safe(uname_machine), safe(sys.platform),
    network_ok, pins_ok, fs_bytes
))
"""


def get_firmware_profile(selection):
    if selection in FIRMWARE_BRANCHES:
        return FIRMWARE_BRANCHES[selection]
    for profile in FIRMWARE_BRANCHES.values():
        if selection == profile["branch"]:
            return profile
    raise ValueError("未知固件分支: " + str(selection))


def build_github_urls(repo, target_dir, branch):
    branch_path = quote(str(branch), safe="")
    target_path = quote(str(target_dir).strip("/"), safe="/")
    return (
        f"https://raw.githubusercontent.com/{repo}/{branch_path}/{target_path}/main.py",
        f"https://api.github.com/repos/{repo}/contents/{target_path}?ref={branch_path}",
    )


def parse_program_version(text, file_names=()):
    match = PROGRAM_VERSION_RE.search(text or "")
    if not match:
        return {"label": "", "version": (), "branch": ""}

    label = match.group("value").strip().strip("\"'")
    number_match = re.match(r"(\d+(?:\.\d+)*)", label)
    version = tuple(
        int(part) for part in number_match.group(1).split(".")
    ) if number_match else ()

    names = {str(name).lower() for name in file_names}
    source_lower = (text or "").lower()
    is_wireless = (
        label.upper().endswith("-W")
        or "wireless_portal" in source_lower
        or "wireless_portal.py" in names
        or "history_store.py" in names
    )
    return {
        "label": label,
        "version": version,
        "branch": "Wireless-Enabled" if is_wireless else "main",
    }


def version_is_at_least(local_info, remote_info):
    local = tuple(local_info.get("version", ()))
    remote = tuple(remote_info.get("version", ()))
    return bool(local and remote and local >= remote)


def version_as_number(info):
    version = tuple(info.get("version", ()))
    if not version:
        return 0.0
    try:
        return float(".".join(str(part) for part in version[:2]))
    except (TypeError, ValueError):
        return 0.0


def version_display(info, missing="未知"):
    label = str(info.get("label", ""))
    return f"v{label}" if label else missing


def runtime_file_order(profile):
    required = tuple(profile["runtime_files"])
    optional = tuple(profile.get("optional_runtime_files", ()))
    return tuple(name for name in required if name != "main.py") + optional + ("main.py",)


def select_runtime_files(profile, files_data):
    by_name = {
        item.get("name"): item
        for item in files_data
        if isinstance(item, dict) and item.get("type") == "file"
    }
    required = tuple(profile["runtime_files"])
    missing = [name for name in required if name not in by_name]
    return [by_name[name] for name in runtime_file_order(profile) if name in by_name], missing


def parse_hardware_probe(output):
    for raw_line in reversed((output or "").splitlines()):
        line = raw_line.strip()
        if not line.startswith(HARDWARE_PROBE_PREFIX + "|"):
            continue
        info = {}
        for field in line.split("|")[1:]:
            if "=" not in field:
                continue
            key, value = field.split("=", 1)
            info[key] = value.strip()
        for key in ("network", "pins_41_42", "fs_bytes"):
            try:
                info[key] = int(info.get(key, 0))
            except (TypeError, ValueError):
                info[key] = 0
        return info
    return None


def hardware_identity(info):
    if not info:
        return "未知硬件"
    values = [
        info.get("build", ""),
        info.get("impl_machine", ""),
        info.get("uname_machine", ""),
    ]
    return next((str(value) for value in values if value), "未知硬件")


def evaluate_hardware_compatibility(profile, info):
    if not info:
        return False, "无法读取开发板身份，已阻止刷入"

    identity = " ".join(str(info.get(key, "")) for key in (
        "build", "impl_machine", "uname_machine", "platform"
    )).upper()
    compact = re.sub(r"[^A-Z0-9]+", "", identity)
    is_waveshare_w = "WAVESHARERP2350BPLUSW" in compact

    if profile["family"] == "rp2040":
        if is_waveshare_w:
            return False, "检测到 Waveshare RP2350B-Plus-W，不能刷入标准版"
        if "RP2040" not in compact:
            return False, "标准版仅支持 RP2040 Pico，当前板型不兼容"
        return True, "RP2040 Pico 与标准版兼容"

    if not is_waveshare_w:
        return False, (
            "无线 W 版仅支持 Waveshare RP2350B-Plus-W；"
            "请先刷入仓库提供的 Waveshare 专用 UF2"
        )
    if not info.get("network"):
        return False, "未检测到 CYW43 network.WLAN，无线固件不兼容"
    if not info.get("pins_41_42"):
        return False, "专板 GPIO41/42 不可用，无线固件不兼容"
    if int(info.get("fs_bytes", 0)) < MIN_WIRELESS_FS_BYTES:
        return False, "文件系统小于 12 MiB，不符合 16 MiB W 版布局"
    return True, "Waveshare RP2350B-Plus-W 与无线 W 版兼容"


HARDWARE_TEST_SCRIPT = """import machine
import time

# --- 全局测试状态记录 ---
test_results = {
    "RTC": False,
    "RTC_Model": "UNKNOWN",
    "SX1276_SPI": False,
    "SX1276_Signal": False
}

def get_serial_number():
    chars = "0123456789ABCDEFGHIJKLMNOPQRSTUVWXYZ"
    try:
        n = int.from_bytes(machine.unique_id(), 'big')
        s = ""
        while n:
            n, r = divmod(n, 36)
            s = chars[r] + s
        s = s or "0"
        if len(s) < 12:
            s = ("0" * (12 - len(s))) + s
        return s[-12:]
    except Exception as e:
        return "S/N INVALID"

print("\\n" + "="*40)
print("开始执行硬件自检 (RTC & SX1276)")
print("="*40)

# --- 1. 检查 RTC ---
print("\\n[0] 正在测试 RTC 模块...")
try:
    i2c = machine.I2C(0, sda=machine.Pin(0), scl=machine.Pin(1), freq=400000)
    devices = i2c.scan()
    if 0x68 in devices:
        print("    [通过] DS3231 芯片检测成功 (I2C地址: 0x68)")
        test_results["RTC"] = True
        test_results["RTC_Model"] = "DS3231"
    elif 0x51 in devices:
        print("    [通过] PCF8563 芯片检测成功 (I2C地址: 0x51)")
        test_results["RTC"] = True
        test_results["RTC_Model"] = "PCF8563"
    else:
        print("    [失败] 未找到 DS3231 (0x68) 或 PCF8563 (0x51)！请检查接线或电源。")
except Exception as e:
    print("    [失败] RTC I2C 通信异常:", e)

# --- 2. 检查 SX1276 ---
SPI_ID = 0
SCK_PIN = 18
MOSI_PIN = 19
MISO_PIN = 16
CS_PIN = 17
RST_PIN = 15
DATA_PIN = 21
CLK_PIN = 20

class SX1276Validator:
    def __init__(self):
        self.spi = machine.SPI(SPI_ID, baudrate=2000000, polarity=0, phase=0,
                               sck=machine.Pin(SCK_PIN), mosi=machine.Pin(MOSI_PIN), miso=machine.Pin(MISO_PIN))
        self.cs = machine.Pin(CS_PIN, machine.Pin.OUT, value=1)
        self.rst = machine.Pin(RST_PIN, machine.Pin.OUT, value=1)

        self.data_in = machine.Pin(DATA_PIN, machine.Pin.IN, machine.Pin.PULL_UP)
        self.clk_in = machine.Pin(CLK_PIN, machine.Pin.IN, machine.Pin.PULL_UP)
        self.bit_samples = []

    def _read_reg(self, reg):
        self.cs.value(0)
        self.spi.write(bytearray([reg & 0x7F]))
        res = self.spi.read(1)[0]
        self.cs.value(1)
        return res

    def _write_reg(self, reg, val):
        self.cs.value(0)
        self.spi.write(bytearray([reg | 0x80, val]))
        self.cs.value(1)

    def hardware_reset(self):
        print("\\n[-] 正在复位 SX1276...")
        self.rst.value(0)
        time.sleep_ms(10)
        self.rst.value(1)
        time.sleep_ms(10)

    def check_spi(self):
        print("\\n[1] 正在测试 SPI 通信...")
        version = self._read_reg(0x42)
        print(f"    -> 读到芯片版本号 (RegVersion): 0x{version:02X}")
        if version in [0x00, 0xFF]:
            print("    [失败] SPI 通信失败！请检查 SCK, MISO, MOSI, CS 接线。")
            return False
        if version == 0x12:
            print("    [通过] 确认芯片为 SX1276/77/78/79 系列。")
        else:
            print("    [注意] 读到版本号正常，但可能不是标准 SX1276 (通常为 0x12)。")

        test_results["SX1276_SPI"] = True
        return True

    def setup_continuous_rx(self):
        print("\\n[2] 正在配置 SX1276 进入 FSK 连续接收模式...")
        self._write_reg(0x01, 0x00)
        time.sleep_ms(10)
        self._write_reg(0x01, 0x01)
        time.sleep_ms(10)

        self._write_reg(0x06, 0xD2)
        self._write_reg(0x07, 0x51)
        self._write_reg(0x08, 0x99)
        self._write_reg(0x31, 0x00)
        self._write_reg(0x40, 0x00)

        self._write_reg(0x01, 0x05)
        time.sleep_ms(50)
        print("    [通过] 射频芯片已启动。")

    def _clk_isr(self, pin):
        if len(self.bit_samples) < 2000:
            self.bit_samples.append(self.data_in.value())

    def analyze_bitstream(self):
        print("\\n[3] 正在挂载时钟中断，捕获比特流...")
        self.bit_samples = []
        self.clk_in.irq(trigger=machine.Pin.IRQ_RISING, handler=self._clk_isr)

        time.sleep(1)
        self.clk_in.irq(handler=None)

        sample_count = len(self.bit_samples)
        print(f"    -> 1秒内捕获到时钟上升沿次数: {sample_count}")

        if sample_count == 0:
            print("    [失败] 没有检测到时钟信号 (CLK)。")
            print("        可能是连续模式未生效，或者 DIO1 未正确连接到 Pico 的引脚 20。")
            return

        print("\\n[4] 开始分析数据流合法性...")
        count_0 = self.bit_samples.count(0)
        count_1 = self.bit_samples.count(1)

        if count_0 == sample_count:
            print("    [失败] 比特流【全为 0】。数据引脚可能接地短路，或射频前端未输出数据。")
        elif count_1 == sample_count:
            print("    [失败] 比特流【全为 1】。数据引脚可能被拉高，或处于死锁状态。")
        else:
            ratio = count_0 / sample_count
            if 0.4 < ratio < 0.6:
                print("    [通过] 比特流分布均匀（0和1各占约一半）。符合无信号时的【背景白噪声】特征。")
            else:
                print("    [通过] 存在 0/1 交替。可能有真实信号正在传输，或者存在定向干扰。")
            test_results["SX1276_Signal"] = True

validator = SX1276Validator()
validator.hardware_reset()
if validator.check_spi():
    validator.setup_continuous_rx()
    validator.analyze_bitstream()

# ================= 最终裁决报告 =================
print("\\n" + "="*40)
print("硬件自检最终报告")
print("="*40)

chip_id = get_serial_number()
print(f"芯片序列号 (S/N): {chip_id}")

failed_components = []
if not test_results["RTC"]:
    failed_components.append("RTC (DS3231/PCF8563 I2C通信失败或未找到设备)")
else:
    print(f"RTC型号: {test_results['RTC_Model']}")
if not test_results["SX1276_SPI"]:
    failed_components.append("SX1276 射频 (SPI通信验证失败)")
elif not test_results["SX1276_Signal"]:
    failed_components.append("SX1276 射频 (射频时钟或信号捕获异常)")

if not failed_components:
    print("\\n[通过] 最终结果: 【全部正常通过】")
    print("所有核心硬件模块均工作在最佳状态！")
else:
    print("\\n[失败] 最终结果: 【未通过】")
    print("报错部件清单:")
    for comp in failed_components:
        print(f"  - {comp}")

print("="*40 + "\\n")
"""
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

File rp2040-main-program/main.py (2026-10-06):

import time
import json
import machine
import os
import gc
import sdcard
import _thread  
import array  
from machine import Pin, ADC, I2C
from lbj_receiver import LBJReceiver, FixedQueue
from ili9341 import ILI9341, BLACK, WHITE, RED, GREEN, BLUE, CYAN, YELLOW, GRAY, MAGENTA
from rtc_ds3231 import DS3231, format_history_time
from boot_post import SystemPOST
from device_protection import DeviceProtection, battery_percent

# 系统性能配置

CPU_FREQ_HZ = 200000000
LOW_BATTERY_CPU_HZ = 18000000
TFT_SPI_BAUD = 60000000
UI_QUEUE_CAPACITY = 16
HISTORY_QUEUE_CAPACITY = 24
HISTORY_RADIO_QUIET_MS = 100
STORAGE_WRITE_GAP_MS = 80
RADIO_CORE_STALL_MS = 10000
RADIO_ERROR_RECOVERY_THRESHOLD = 3
RADIO_AUTO_RECOVERY_ENABLED = True
RADIO_HEALTH_LOG_MS = 60000
BUTTON_BEEP_MS = 25

pin_bl = Pin(6, Pin.OUT, value=0)
machine.freq(CPU_FREQ_HZ)
try:
    print("BOOT_RESET_CAUSE", machine.reset_cause())
except Exception:
    pass
Program_ver = "5.13"
is_es_ver = 0 
Author_Name = "MisakaXing"
BAT_OFFSET = 0.174 

ui_queue = FixedQueue(UI_QUEUE_CAPACITY)
history_queue = FixedQueue(HISTORY_QUEUE_CAPACITY)
sd_log_queue = FixedQueue(HISTORY_QUEUE_CAPACITY)
ui_lock = _thread.allocate_lock() 
RADIO_HEARTBEAT = 0
RADIO_CONSECUTIVE_ERRORS = 1
RADIO_TOTAL_ERRORS = 2
RADIO_LAST_ERROR_LOG = 3
RADIO_RUNNING = 4
RADIO_STOPPED = 5
RADIO_BUSY = 6
radio_state = [time.ticks_ms(), 0, 0, 0, True, True, False]
last_radio_health_log = 0
last_storage_write = 0

last_hw_update = 0  
last_rssi_str = "N/A" 
hist_rssi_str = "N/A" # 用于单独储存历史记录的 RSSI
screen_is_on = True 
last_battery_v = None
last_battery_p = None
last_temp_str = None
last_vbus_display = None
last_usb_power = False
last_usb_update = None
last_hw_draw = None
HW_SAMPLE_INTERVAL_MS = 5000
USB_SAMPLE_INTERVAL_MS = 1000
low_battery_shutdown = False
top_bar_ready = False
last_top_status = None
protection = DeviceProtection()

# 1. 硬件 IO 初始化

tft_cs = Pin(9, Pin.OUT, value=1) 
_boot_display = globals().pop('_boot_display', None)
boot_started_ms = None
boot_first_frame_ms = None
if _boot_display is not None:
    spi1, tft, boot_started_ms, boot_first_frame_ms = _boot_display
else:
    # Older installations without boot.py keep the original startup path.
    spi1 = machine.SPI(1, baudrate=20000000, sck=Pin(10), mosi=Pin(11), miso=Pin(8, Pin.IN, Pin.PULL_UP))
    tft = ILI9341(spi1, cs=9, dc=12, rst=13)
del _boot_display
spi1.init(baudrate=TFT_SPI_BAUD, polarity=0, phase=0)

sd_cs = Pin(7, Pin.OUT, value=1)
bat_en = Pin(14, Pin.OUT, value=1)
bat_adc = ADC(Pin(27)) 
vbus_sense = Pin(24, Pin.IN)
buzzer = Pin(22, Pin.OUT, value=0)

i2c0 = I2C(0, sda=Pin(0), scl=Pin(1), freq=400000)
rtc = DS3231(i2c0)

btn_menu, btn_up, btn_down, btn_ok = [Pin(i, Pin.IN, Pin.PULL_UP) for i in (2, 3, 4, 5)]
btn_wake = Pin(28, Pin.IN, Pin.PULL_UP)
sensor_temp = machine.ADC(4)


class ButtonTracker:
    def __init__(self, pin, repeat=False, debounce_ms=12,
                 repeat_delay_ms=350, repeat_interval_ms=120):
        self.pin = pin
        self.repeat = repeat
        self.debounce_ms = debounce_ms
        self.repeat_delay_ms = repeat_delay_ms
        self.repeat_interval_ms = repeat_interval_ms
        self.raw_pressed = not pin.value()
        self.stable_pressed = self.raw_pressed
        self.changed_at = time.ticks_ms()
        self.repeat_at = time.ticks_add(self.changed_at, repeat_delay_ms)

    def poll(self, now):
        raw_pressed = not self.pin.value()
        if raw_pressed != self.raw_pressed:
            self.raw_pressed = raw_pressed
            self.changed_at = now

        if (
            self.raw_pressed != self.stable_pressed
            and time.ticks_diff(now, self.changed_at) >= self.debounce_ms
        ):
            self.stable_pressed = self.raw_pressed
            if self.stable_pressed:
                self.repeat_at = time.ticks_add(now, self.repeat_delay_ms)
                return True
            return False

        if (
            self.repeat
            and self.raw_pressed
            and self.stable_pressed
            and time.ticks_diff(now, self.repeat_at) >= 0
        ):
            self.repeat_at = time.ticks_add(now, self.repeat_interval_ms)
            return True
        return False

# 显示只运行在核心 0，驱动内部已经分块发送，无需人为 sleep 或二次切片。
def safe_fill_rect(x, y, w, h, color):
    tft.fill_rect(x, y, w, h, color)

LOCO_NAME_GBK = {
    "轨道探伤车": b"\xb9\xec\xb5\xc0\xcc\xbd\xc9\xcb\xb3\xb5",
    "起重轨道车": b"\xc6\xf0\xd6\xd8\xb9\xec\xb5\xc0\xb3\xb5",
    "轨道打磨车": b"\xb9\xec\xb5\xc0\xb4\xf2\xc4\xa5\xb3\xb5",
    "解放": b"\xbd\xe2\xb7\xc5",
    "前进": b"\xc7\xb0\xbd\xf8",
    "建设": b"\xbd\xa8\xc9\xe8",
    "蓝箭控车": b"\xc0\xb6\xbc\xfd\xbf\xd8\xb3\xb5",
    "北京": b"\xb1\xb1\xbe\xa9",
    "北京宽": b"\xb1\xb1\xbe\xa9\xbf\xed",
    "轻油": b"\xc7\xe1\xd3\xcd",
    "天安": b"\xcc\xec\xb0\xb2",
    "新曙光": b"\xd0\xc2\xca\xef\xb9\xe2",
    "神州": b"\xc9\xf1\xd6\xdd",
    "DJ熊猫": b"DJ\xd0\xdc\xc3\xa8",
    "蓝箭动车": b"\xc0\xb6\xbc\xfd\xb6\xaf\xb3\xb5",
    "先锋号": b"\xcf\xc8\xb7\xe6\xba\xc5",
    "天梭": b"\xcc\xec\xcb\xf3",
    "DJ4和谐": b"DJ4\xba\xcd\xd0\xb3",
}
UNKNOWN_LOCO_GBK = b"\xce\xb4\xd6\xaa"

def encode_loco_gbk(loco):
    """Encode the mixed Chinese/ASCII locomotive label for HZK16."""
    loco = str(loco)

    if loco.startswith("UNK("):
        return UNKNOWN_LOCO_GBK + loco[3:].encode()
    if loco.startswith("未知("):
        return UNKNOWN_LOCO_GBK + loco[2:].encode()

    separator = loco.find("-")
    name = loco if separator < 0 else loco[:separator]
    suffix = b"" if separator < 0 else loco[separator:].encode()
    name_gbk = LOCO_NAME_GBK.get(name)
    if name_gbk is not None:
        return name_gbk + suffix

    return loco.encode()

def get_serial_number():
    chars = "0123456789ABCDEFGHIJKLMNOPQRSTUVWXYZ"

    try:
        n = int.from_bytes(machine.unique_id(), 'big')#读取芯片唯一ID

        # Base36
        s = ""
        while n:
            n, r = divmod(n, 36)
            s = chars[r] + s

        s = s or "0"

        # 固定12位，前补0
        if len(s) < 12:
            s = ("0" * (12 - len(s))) + s

        # 超过12位截取后12位
        return s[-12:]

    except Exception as e:
        print(e)
        return "S/N INVALID"



# 2. 系统全局变量
Serial_Number = get_serial_number()
MAX_HIST = 2000
HISTORY_RESERVE_BYTES = 16 * 1024
HIST_FILE = "history.jsonl"
SD_LOG_FILE = "/sd/lbj_log.jsonl"
CONFIG_FILE = "config.json"
PPM_CALIBRATION_VERSION = 7

system_state = "DASHBOARD" 
has_received = False
menu_index = 0

cfg_scr_idx = 3 
SCR_OFF_OPTS = ["30s", "1min", "5min", "never", "on demand"]
SCR_OFF_MS = [30000, 60000, 300000, -1, -1]
SCR_OFF_ON_DEMAND_INDEX = 4
cfg_buzzer = True
cfg_ppm_offset = 6.0
cfg_ppm_calibrated = False

menu_items = ["BUZZER: ON", "SET DATE", "JUMP TO ID", "FORMAT FLASH", "FORMAT SD", "MOUNT SD", "ABOUT DEV", f"SCREEN OFF AFTER: {SCR_OFF_OPTS[cfg_scr_idx]}"]

hist_ptr = -1
total_count = 0

history_offsets = array.array('I') 
history_block_reason = None
history_free_bytes = None
last_interaction = time.ticks_ms()
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

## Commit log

2026-04-18 added offset for bat-vol adc
2026-04-18 fix sd card hotplug
    [main.py]
2026-04-19 added support to read log in pico
2026-04-20 added dual core support,improve stability
    [lbj_receiver.py, main.py]
2026-04-21 SD Hotplug deprecated to improve stability
    [main.py]
2026-04-21 added interrupt
2026-04-23 stability fix added force download
    [main.py]
2026-04-24 added PCB
    [BOM-Chart.xlsx]
2026-04-24 add power alert
2026-04-24 Added Case
    [RP2040-LBJ-RECEIVER CASE.stl, RP2040LBJRECEIVER CASE.f3d, RP2040LBJRECEIVER CASE.step]
2026-05-26 fix SS9 display error
    [BOM-Chart.xlsx]
2026-06-01 replace SN with RP2350 ChipID
    [main.py]
2026-06-02 multiple updates
    [BOM-Chart.xlsx, RP2040-LBJ-RECEIVER CASE.stl, RP2040LBJRECEIVER CASE v10.stl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]
2026-06-04 fix unknown loco bug
    [lbj_receiver.py]
2026-06-11 added auto freq correction based on FEI
    [lbj_receiver.py, main.py]
2026-06-12 fix RTC NOT SYNC ERR
    [main.py, rtc_ds3231.py]
2026-06-13 replace UNK as standard chinese
    [lbj_receiver.py, main.py]
2026-06-13 fix pcf8563 rtc ERR
    [main.py, rtc_ds3231.py]
2026-06-14 fix traintype decode err
    [lbj_receiver.py, main.py]
2026-08-30 Release 5.2: retain BASIC records with missing measurements
    [lbj_receiver.py, main.py]
2026-09-08 Fix large history downloads in log viewer
    [test_pico_history.py, test_viewer_transfer.py]
2026-09-20 modify case
    [CASE_V13_BODY_PCB_CLEARANCE_0p25.stl, CASE_V13_TOP_SCREEN_EDGE_IN0p7_TOTAL.stl, RP2040LBJRECEIVER CASE v10.stl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]
2026-10-04 Release 5.11: add DMA capture, AFC recovery and device protection
2026-10-06 Replace PicoUpdater and LogViewer with unified LBJ Manager
    [drag_drop_smoke.py, frozen_smoke.py, gui_smoke.py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]
2026-10-06 Fix cross-platform navigation shortcuts matching mouse clicks
    [gui_smoke.py, lbj_manager.py, test_integration.py]
2026-10-06 Fix Windows post-flash reset and verify USB re-enumeration
    [lbj_manager.py, test_reboot.py]
2026-10-06 Set POST battery LOW upper threshold to 3.6V
